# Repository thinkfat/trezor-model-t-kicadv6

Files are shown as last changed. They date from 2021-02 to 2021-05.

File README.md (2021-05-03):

# trezor-model-t-kicadv6

This is an adaptation of the official Trezor Model T PCB to KiCAD. 
It was created in response to an EEVBlog episode where Dave tested
whether releasing the PCB CAD files (instead of Gerber files) for 
an Open Hardware project was enough to actually recreate the PCB.

This is not a ready-to-manufacture project. It is also not identical
to the genuine Trezor T PCB. Several changes have been made by myself to
loosen the manufacturing constraints of the PCB and improve the routing
for EMC compliance.

This PCB has never been actually manufactured. Use it on your own risk 
as a starting point to make your own Trezor Model T.

I have neither plans or intention to continue this work.

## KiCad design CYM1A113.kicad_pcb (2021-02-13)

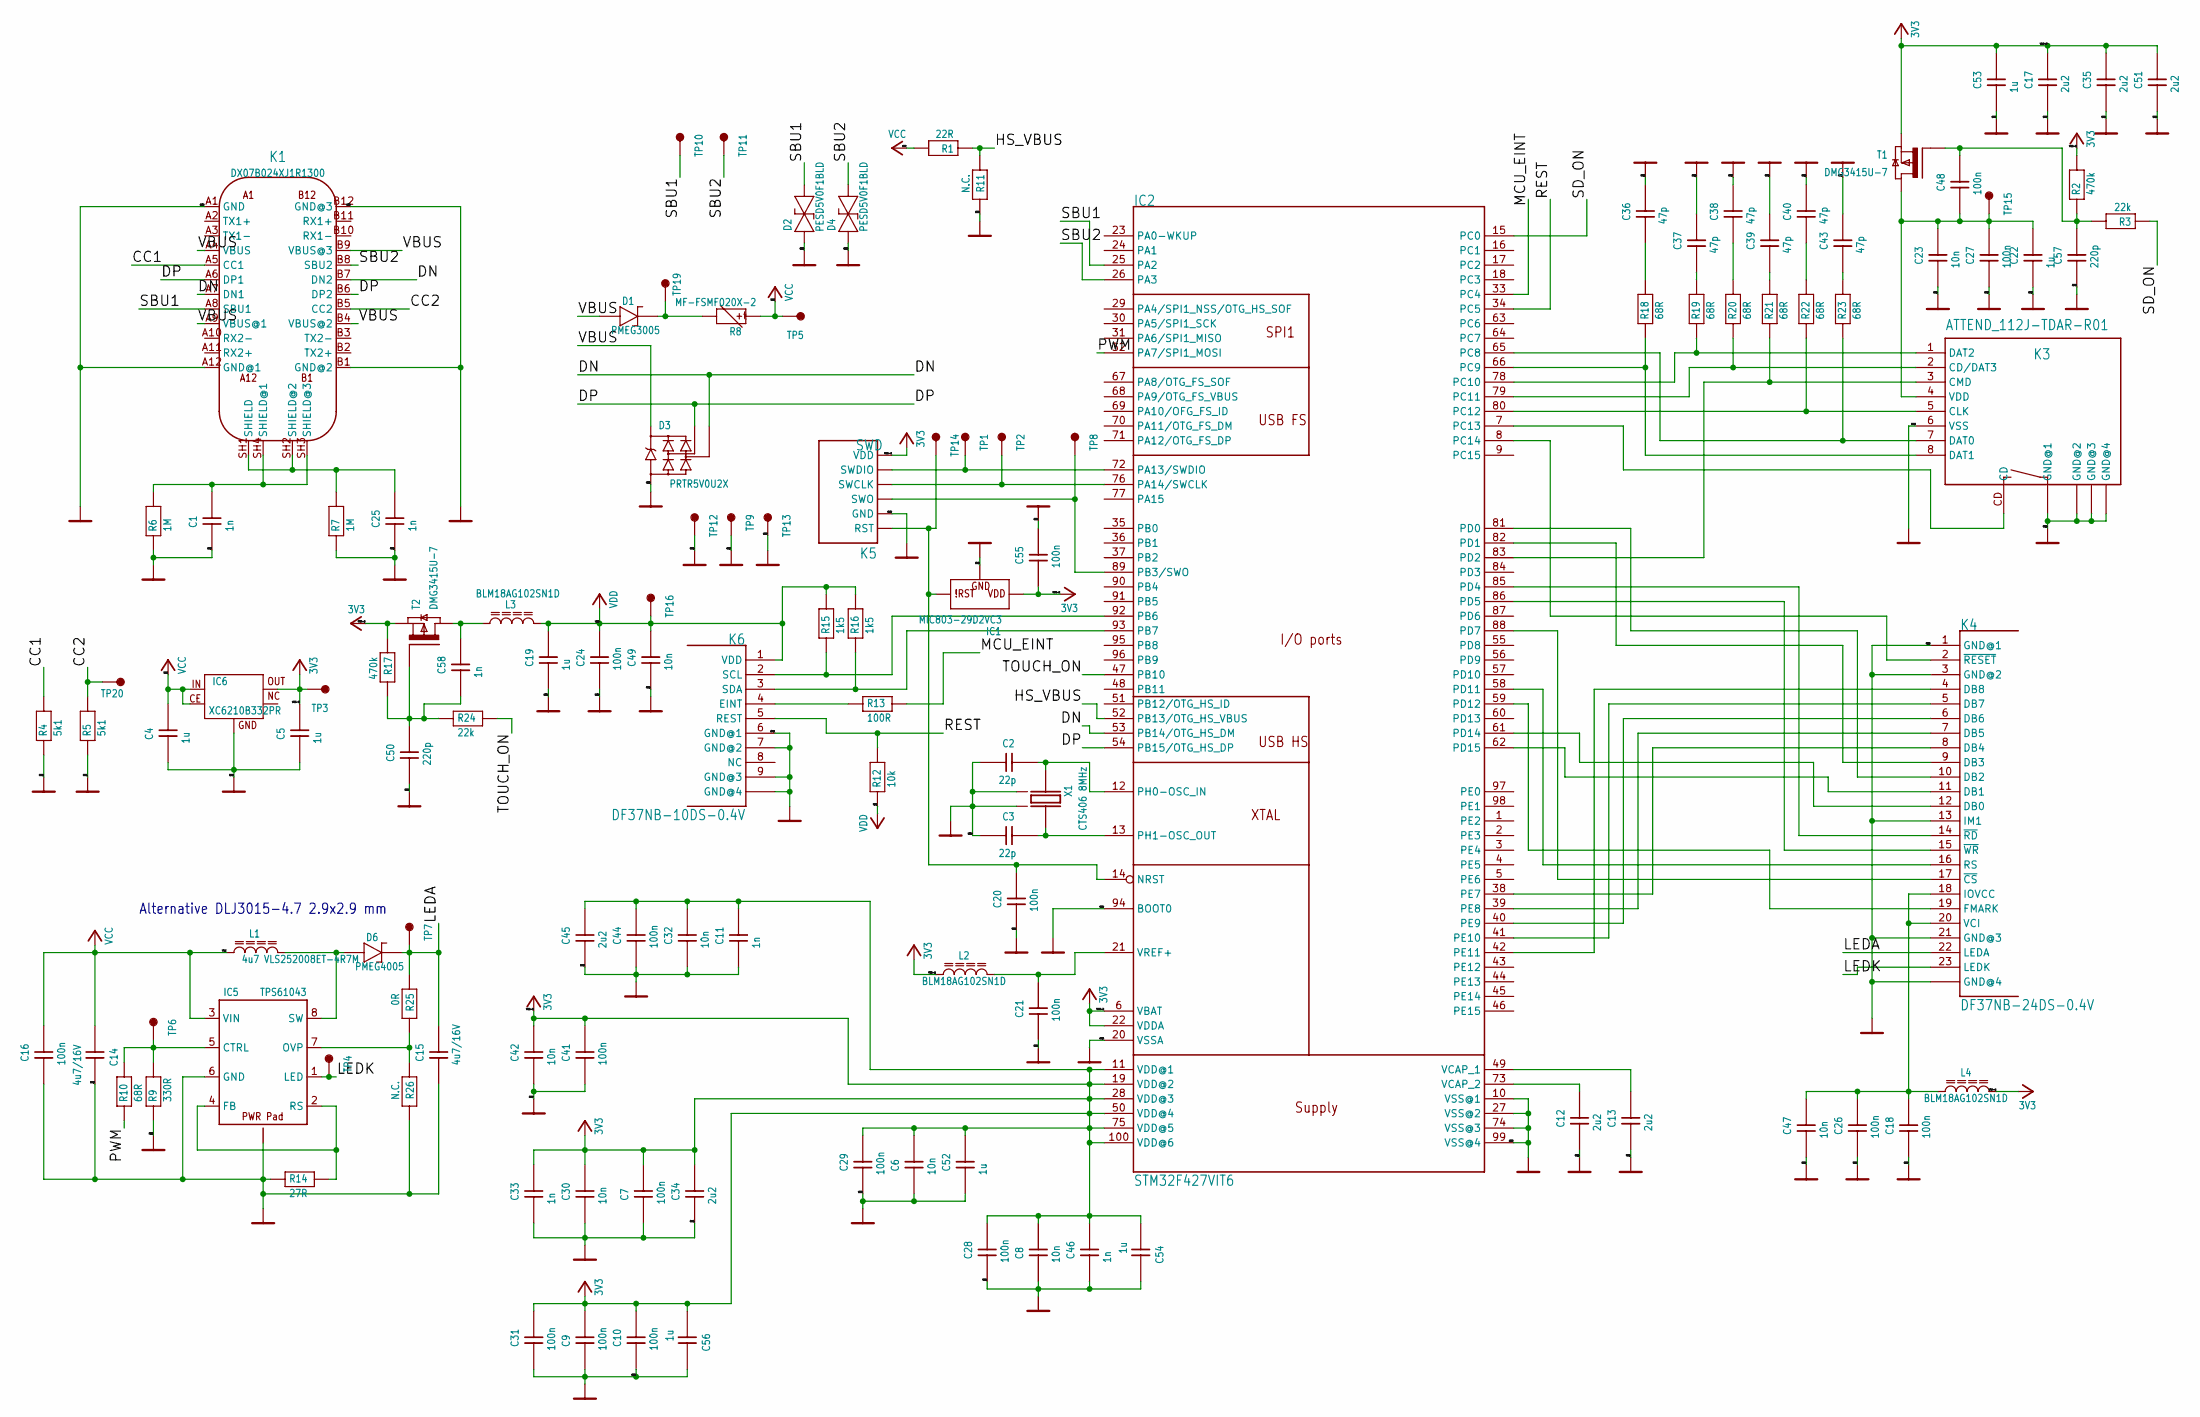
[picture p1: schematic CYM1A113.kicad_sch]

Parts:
C1, C11, C25, C33, C46, C58: 1n; 0402
C2, C3: 22p; 0402
C4, C19, C22, C52, C53, C54, C56: 1u; 0603_REFLOW
C5: 1u; 0603
C6, C8, C23, C30, C32, C42, C47, C49: 10n; 0402
C7, C9, C10, C16, C18, C20, C21, C24, C26, C27, C28, C29, C31, C41, C44, C48, C55: 100n; 0402
C12, C13, C17, C34, C35, C45, C51: 2u2; 0805_REFLOW
C14, C15: 4u7/16V; 0805_REFLOW
C36, C37, C38, C39, C40, C43: 47p; 0402
C50, C57: 220p; 0402
D1: PMEG3005; SOD323F
D2, D4: PESD5V0F1BLD; SOD882D
D3: PRTR5V0U2X; SOT143B_REFLOW
D6: PMEG4005; SOD323F
IC1: MIC803-29D2VC3; SOT23_MEDIUM_SIZE
IC2: STM32F427VIT6; LQFP100_NO_CENTER_NO_TDOCU
IC5: TPS61043; WSON-8_3X3MM
IC6: XC6210B332PR; SOT89-5
K1: DX07B024XJ1R1300; USB_C_JAE_DX07B024XJ1
K3: ATTEND_112J-TDAR-R01; ATTEND_112J-TXAR-R01_SMALL
K4: DF37NB-24DS-0.4V
K5: SWD
K6: DF37NB-10DS-0.4V
L1: 4u7 VLS252008ET-4R7M; L_2.5X2.0
L2, L3, L4: BLM18AG102SN1D; 0603_REFLOW
R1: 22R; 0402
R2, R17: 470k; 0402
R3, R24: 22k; 0402
R4, R5: 5k1; 0402
R6, R7: 1M; 0402
R8: MF-FSMF020X-2; 0603
R9: 330R; 0402
R10, R18, R19, R20, R21, R22, R23: 68R; 0402
R11, R26: N.C.; 0402
R12: 10k; 0402
R13: 100R; 0402
R14: 27R; 0402
R15, R16: 1k5; 0402
R25: 0R; 0402
T1, T2: DMG3415U-7; SOT23_REFLOW
TP1, TP2, TP4, TP6, TP7, TP8, TP9, TP12, TP13, TP14, TP15, TP16: MB_1.27; MB1.27
TP3, TP5, TP10, TP11: MB_1.50; MB1.5
TP19, TP20: MB_1.00
X1: CTS406 8MHz; X6,0X3,5

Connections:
/CC1: K1.A5 (CC1), R4.P$2 (2)
/CC2: K1.B5 (CC2), R5.P$2 (2), TP20.1
/DN: D3.3 (I/O2), IC2.53 (PB14/OTG_HS_DM), K1.A7 (DN1), K1.B7 (DN2)
/DP: D3.2 (I/O1), IC2.54 (PB15/OTG_HS_DP), K1.A6 (DP1), K1.B6 (DP2)
/HS_VBUS: IC2.52 (PB13/OTG_HS_VBUS), R1.P$1 (1), R11.P$1 (1)
/LEDA: C15.2, D6.K (2), K4.22 (LEDA), R25.P$1 (1), TP7.1
/LEDK: IC5.1 (LED), K4.23 (LEDK), TP4.1
/MCU_EINT: IC2.33 (PC4), R13.P$2 (2)
/PWM: IC2.32 (PA7/SPI1_MOSI), R10.P$1 (1)
/REST: IC2.34 (PC5), K6.5 (REST), R12.P$2 (2)
/SBU1: D2.2, IC2.25 (PA2), K1.A8 (SBU1), TP10.1
/SBU2: D4.2, IC2.26 (PA3), K1.B8 (SBU2), TP11.1
/SD_ON: IC2.15 (PC0), R3.P$1 (1)
/TOUCH_ON: IC2.47 (PB10), R24.P$2 (2)
/VBUS: D1.A (1), D3.4 (VCC), K1.A4 (VBUS), K1.A9 (VBUS@1), K1.B4 (VBUS@2), K1.B9 (VBUS@3)
GND: C1.P$1 (1), C2.P$1 (1), C3.P$1 (1), C4.1, C5.1, C6.P$1 (1), C7.P$1 (1), C8.P$1 (1), C9.P$1 (1), C10.P$1 (1), C11.P$1 (1), C12.1, C13.1, C14.2, C15.1, C16.P$1 (1), C17.1, C18.P$1 (1), C19.1, C20.P$1 (1), C21.P$1 (1), C22.1, C23.P$1 (1), C24.P$1 (1), C25.P$1 (1), C26.P$1 (1), C27.P$1 (1), C28.P$1 (1), C29.P$1 (1), C30.P$1 (1), C31.P$1 (1), C32.P$1 (1), C33.P$1 (1), C34.1, C35.1, C36.P$2 (2), C37.P$2 (2), C38.P$2 (2), C39.P$2 (2), C40.P$2 (2), C41.P$1 (1), C42.P$1 (1), C43.P$2 (2), C44.P$1 (1), C45.1, C46.P$1 (1), C47.P$1 (1), C49.P$1 (1), C50.P$1 (1), C51.1, C52.1, C53.1, C54.2, C55.P$2 (2), C56.2, C57.P$1 (1), D2.1, D3.1 (GND), D4.1, IC1.1 (GND), IC2.10 (VSS@1), IC2.20 (VSSA), IC2.27 (VSS@2), IC2.74 (VSS@3), IC2.94 (BOOT0), IC2.99 (VSS@4), IC5.6 (GND), IC5.EP, IC5.EP$1 (EP), IC5.EP$2 (EP), IC5.EP$3 (EP), IC5.EP$4 (EP), IC6.2 (GND), K1.A1 (GND), K1.A12 (GND@1), K1.B1 (GND@2), K1.B12 (GND@3), K3.6 (VSS), K3.GND@1, K3.GND@2, K3.GND@3, K3.GND@4, K4.1 (GND@1), K4.3 (GND@2), K4.13 (IM1), K4.21 (GND@3), K4.24 (GND@4), K4.25 (GND@4), K4.26 (GND@4), K5.GND, K6.6 (GND@1), K6.7 (GND@2), K6.9 (GND@3), K6.10 (GND@4), K6.11 (GND@4), K6.12 (GND@4), R4.P$1 (1), R5.P$1 (1), R6.P$1 (1), R7.P$1 (1), R9.P$1 (1), R11.P$2 (2), R14.P$1 (1), R26.P$2 (2), TP9.1, TP12.1, TP13.1, X1.2 (GND1), X1.4 (GND2)
unnamed: C1.P$2 (2), K1.SH3 (SHIELD@3), K1.SH4 (SHIELD@1), R6.P$2 (2)
unnamed: C2.P$2 (2), IC2.12 (PH0-OSC_IN), X1.1
unnamed: C3.P$2 (2), IC2.13 (PH1-OSC_OUT), X1.3 (2)
unnamed: C12.2, IC2.73 (VCAP_2)
unnamed: C13.2, IC2.49 (VCAP_1)
unnamed: C18.P$2 (2), C26.P$2 (2), C47.P$2 (2), K4.18 (IOVCC), K4.20 (VCI), L4.1
unnamed: C20.P$2 (2), IC1.2 (RES), IC2.14 (NRST), K5.RST, TP14.1
unnamed: C21.P$2 (2), IC2.21 (VREF+), L2.2
unnamed: C22.2, C23.P$2 (2), C27.P$2 (2), C48.P$1 (1), K3.4 (VDD), T1.3 (D), TP15.1
unnamed: C25.P$2 (2), K1.SH1 (SHIELD), K1.SH2 (SHIELD@2), R7.P$2 (2)
unnamed: C36.P$1 (1), R18.P$2 (2)
unnamed: C37.P$1 (1), R19.P$2 (2)
unnamed: C38.P$1 (1), R20.P$2 (2)
unnamed: C39.P$1 (1), R21.P$2 (2)
unnamed: C40.P$1 (1), R22.P$2 (2)
unnamed: C43.P$1 (1), R23.P$2 (2)
unnamed: C48.P$2 (2), C57.P$2 (2), R2.P$1 (1), R3.P$2 (2), T1.2 (G)
unnamed: C50.P$2 (2), C58.P$1 (1), R17.P$2 (2), R24.P$1 (1), T2.2 (G)
unnamed: C58.P$2 (2), L3.1, T2.3 (D)
unnamed: D1.K (2), R8.2, TP19.1
unnamed: D6.A (1), IC5.8 (SW), L1.2
unnamed: IC2.7 (PC13), K3.CD
unnamed: IC2.8 (PC14), K4.2 (~RESET)
unnamed: IC2.38 (PE7), K4.8 (DB4)
unnamed: IC2.39 (PE8), K4.7 (DB5)
unnamed: IC2.40 (PE9), K4.6 (DB6)
unnamed: IC2.41 (PE10), K4.5 (DB7)
unnamed: IC2.42 (PE11), K4.4 (DB8)
unnamed: IC2.58 (PD11), K4.16 (RS)
unnamed: IC2.59 (PD12), K4.19 (FMARK)
unnamed: IC2.61 (PD14), K4.12 (DB0)
unnamed: IC2.62 (PD15), K4.11 (DB1)
unnamed: IC2.65 (PC8), K3.7 (DAT0), R23.P$1 (1)
unnamed: IC2.66 (PC9), K3.8 (DAT1), R18.P$1 (1)
unnamed: IC2.72 (PA13/SWDIO), K5.SWDIO, TP1.1
unnamed: IC2.76 (PA14/SWCLK), K5.SWCLK, TP2.1
unnamed: IC2.78 (PC10), K3.1 (DAT2), R19.P$1 (1)
unnamed: IC2.79 (PC11), K3.2 (CD/DAT3), R20.P$1 (1)
unnamed: IC2.80 (PC12), K3.5 (CLK), R22.P$1 (1)
unnamed: IC2.81 (PD0), K4.10 (DB2)
unnamed: IC2.82 (PD1), K4.9 (DB3)
unnamed: IC2.83 (PD2), K3.3 (CMD), R21.P$1 (1)
unnamed: IC2.85 (PD4), K4.14 (~RD)
unnamed: IC2.86 (PD5), K4.15 (~WR)
unnamed: IC2.88 (PD7), K4.17 (~CS)
unnamed: IC2.89 (PB3/SWO), K5.SWO, TP8.1
unnamed: IC2.92 (PB6), K6.2 (SCL), R15.P$1 (1)
unnamed: IC2.93 (PB7), K6.3 (SDA), R16.P$1 (1)
unnamed: IC5.2 (RS), IC5.4 (FB), R14.P$2 (2)
unnamed: IC5.5 (CTRL), R9.P$2 (2), R10.P$2 (2), TP6.1
unnamed: IC5.7 (OVP), R25.P$2 (2), R26.P$1 (1)
unnamed: K6.4 (EINT), R13.P$1 (1)
VBAT: C19.2, C24.P$2 (2), C49.P$2 (2), K6.1 (VDD), L3.2, R12.P$1 (1), R15.P$2 (2), R16.P$2 (2), TP16.1
VCC: C4.2, C14.1, C16.P$2 (2), IC5.3 (VIN), IC6.1 (CE), IC6.4 (IN), L1.1, R1.P$2 (2), R8.1, TP5.1
VCC-2: C5.2, C6.P$2 (2), C7.P$2 (2), C8.P$2 (2), C9.P$2 (2), C10.P$2 (2), C11.P$2 (2), C17.2, C28.P$2 (2), C29.P$2 (2), C30.P$2 (2), C31.P$2 (2), C32.P$2 (2), C33.P$2 (2), C34.2, C35.2, C41.P$2 (2), C42.P$2 (2), C44.P$2 (2), C45.2, C46.P$2 (2), C51.2, C52.2, C53.2, C54.1, C55.P$1 (1), C56.1, IC1.3 (VDD), IC2.6 (VBAT), IC2.11 (VDD@1), IC2.19 (VDD@2), IC2.22 (VDDA), IC2.28 (VDD@3), IC2.50 (VDD@4), IC2.75 (VDD@5), IC2.100 (VDD@6), IC6.5 (OUT), K5.VCC (VDD), L2.1, L4.2, R2.P$2 (2), R17.P$1 (1), T1.1 (S), T2.1 (S), TP3.1

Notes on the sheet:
Alternative DLJ3015-4.7 2.9x2.9 mm

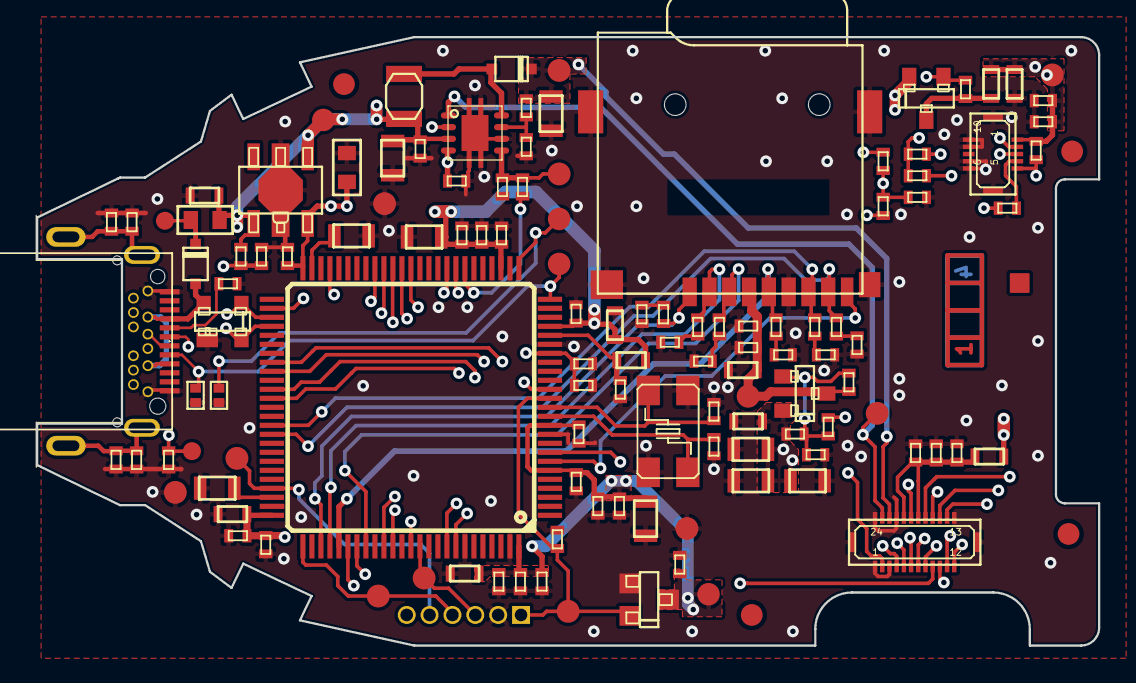
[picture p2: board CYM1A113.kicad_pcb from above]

Board: 4 copper layers, 59.0 x 33.8 mm, 123 parts (0 on the bottom side), 71 nets.

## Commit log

2021-02-12 Initial commit of Trezor Model T schematics and PCB
    Imported from the original Eagle project files
    Cleanup of footprints and vias
    Setup of design rules to match the board
    [CYM1A113.kicad_pcb, CYM1A113.kicad_sch]
2021-02-13 Get rid of blind and micro vias
    Use regular through-vias, there's no need to go "micro" or even blind
    Add manufactoring constraings matching JLCPCB 4-layer process.
    All DRC violations resolved except around the USB-C receptacle. The
    chosen part doesn't fit into JLCPCBs capabilities due to hole-hole
    and hole-copper constraints.
    [CYM1A113.kicad_pcb]
2021-02-13 Routing improvements.
    Move the display traces away from the first inner layer to
    keep it as an unbroken ground plane. This eliminates most of the
    jumper traces, still using the first inner layer as reference plane
    for display and touchscreen signal.
    [CYM1A113.kicad_pcb]
